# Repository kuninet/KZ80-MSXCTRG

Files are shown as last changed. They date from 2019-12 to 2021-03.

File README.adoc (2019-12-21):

== KZ80シリーズ MSX カートリッジスロットボード

=== 概要
* SBC8080バスなどに接続する MSX ROMカセット カートリッジスロットボードですです。試作段階です。

=== 注意
* KZ80-CPUB REV3 のZ80専用信号線バスと、KZ80-IOB REV2以降(アドレスデコードの関係で...)のAポートを使用します。またメモリーボードKZ80-1MSRAMのパターンカット等の改造が必要です。

=== ライセンス
* 本プロジェクトのデータはMITライセンスのもとで公開します。

=== 参考
* http://ngs.no.coocan.jp/doc/wiki.cgi/datapack?page=7%BE%CF+MSX2%2B%B2%F3%CF%A9%CE%E3

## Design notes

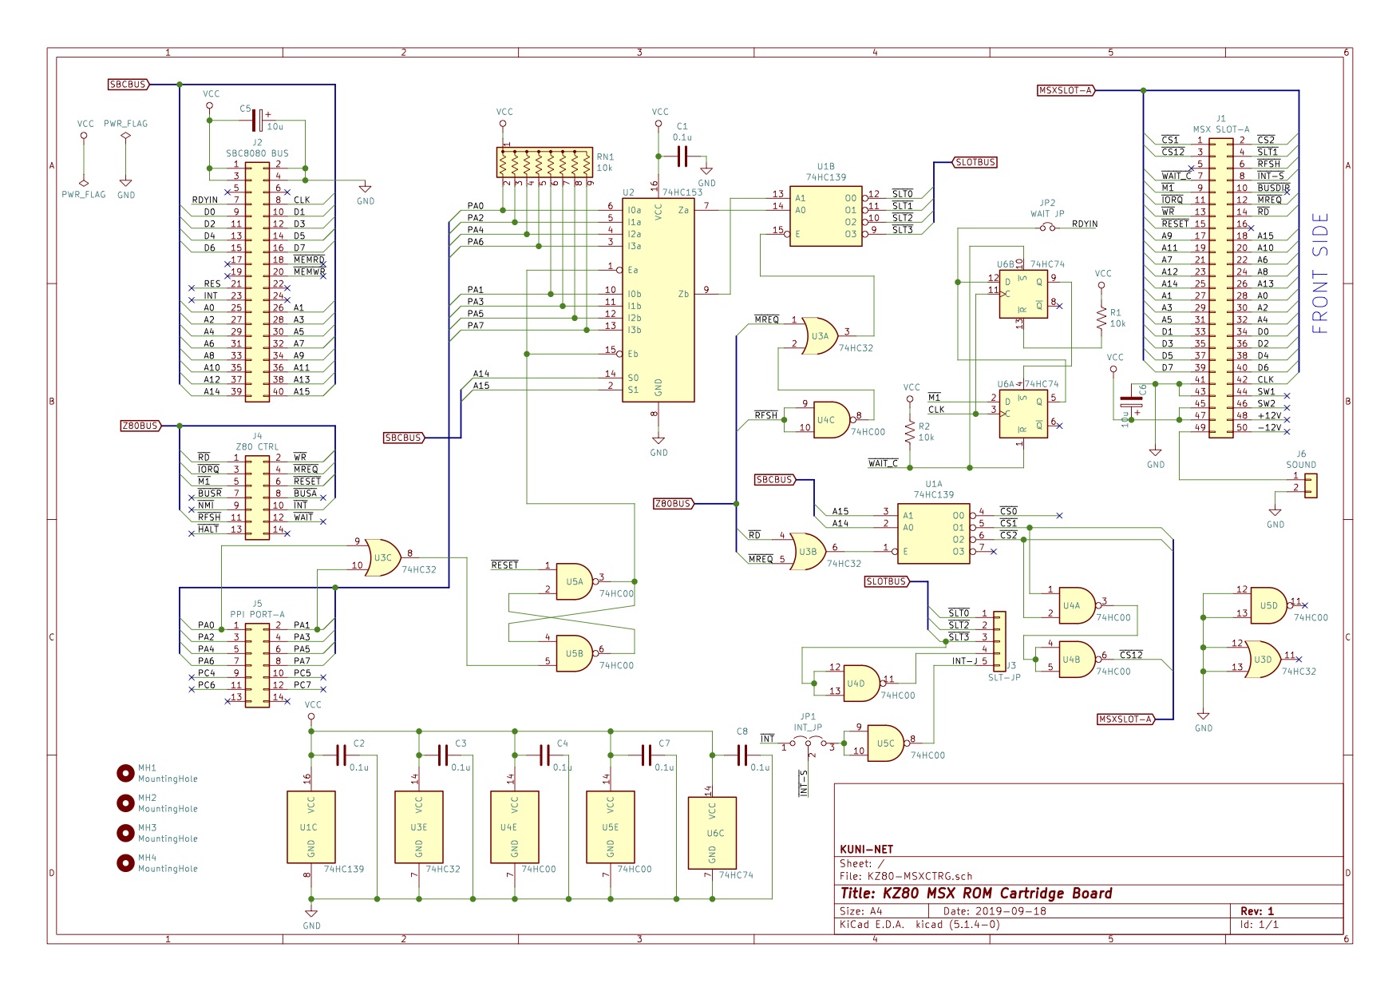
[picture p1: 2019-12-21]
image/KZ80-MSXCTRG-REV1.jpg

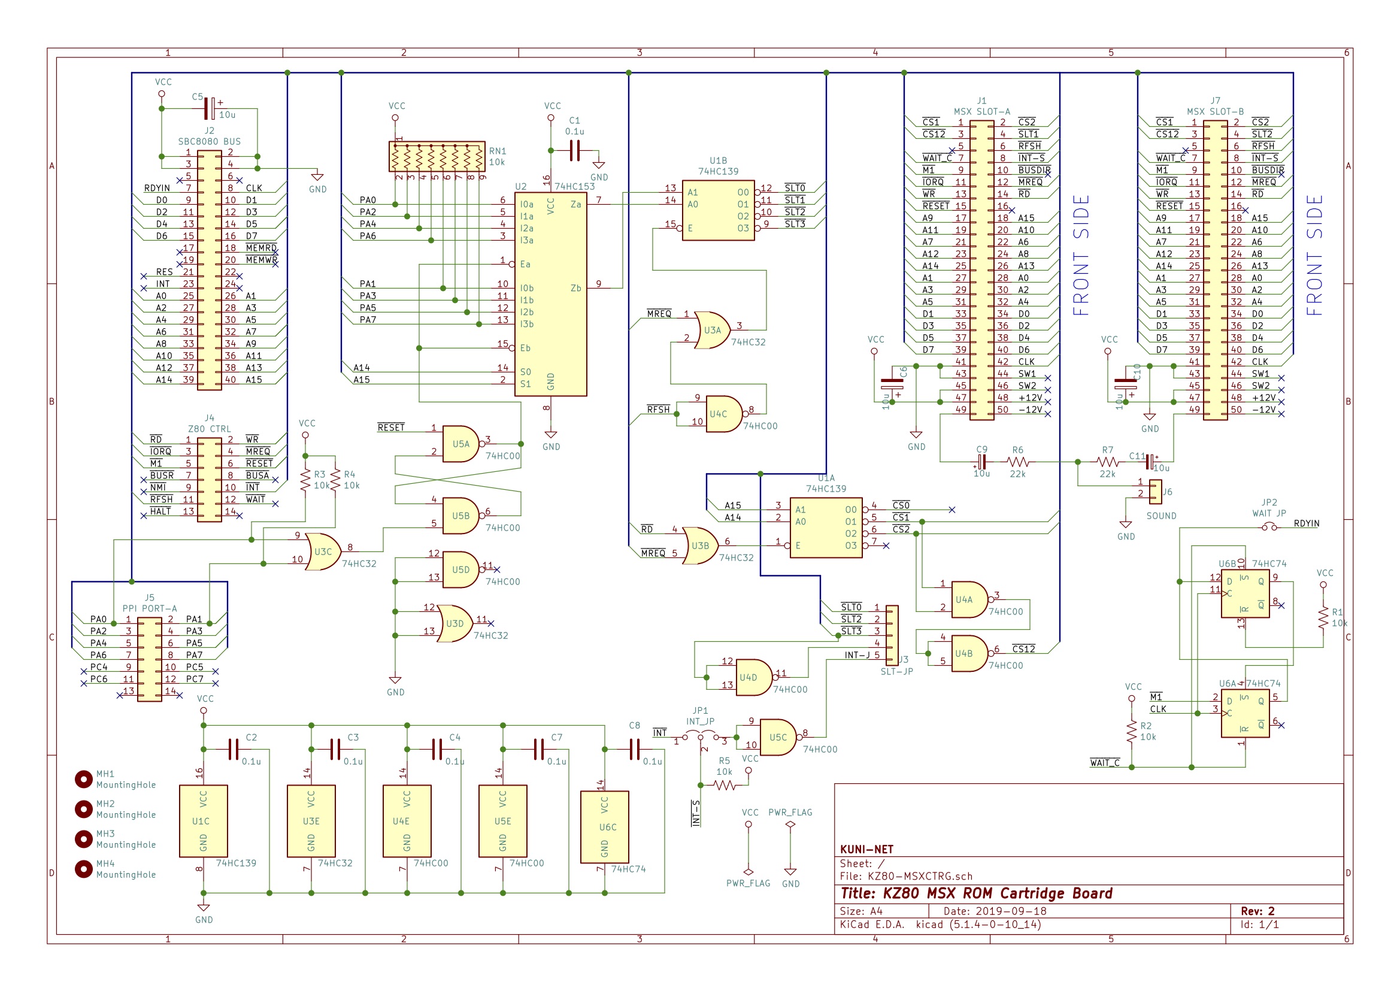
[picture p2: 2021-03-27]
image/KZ80-MSXCTRG-REV2.jpg

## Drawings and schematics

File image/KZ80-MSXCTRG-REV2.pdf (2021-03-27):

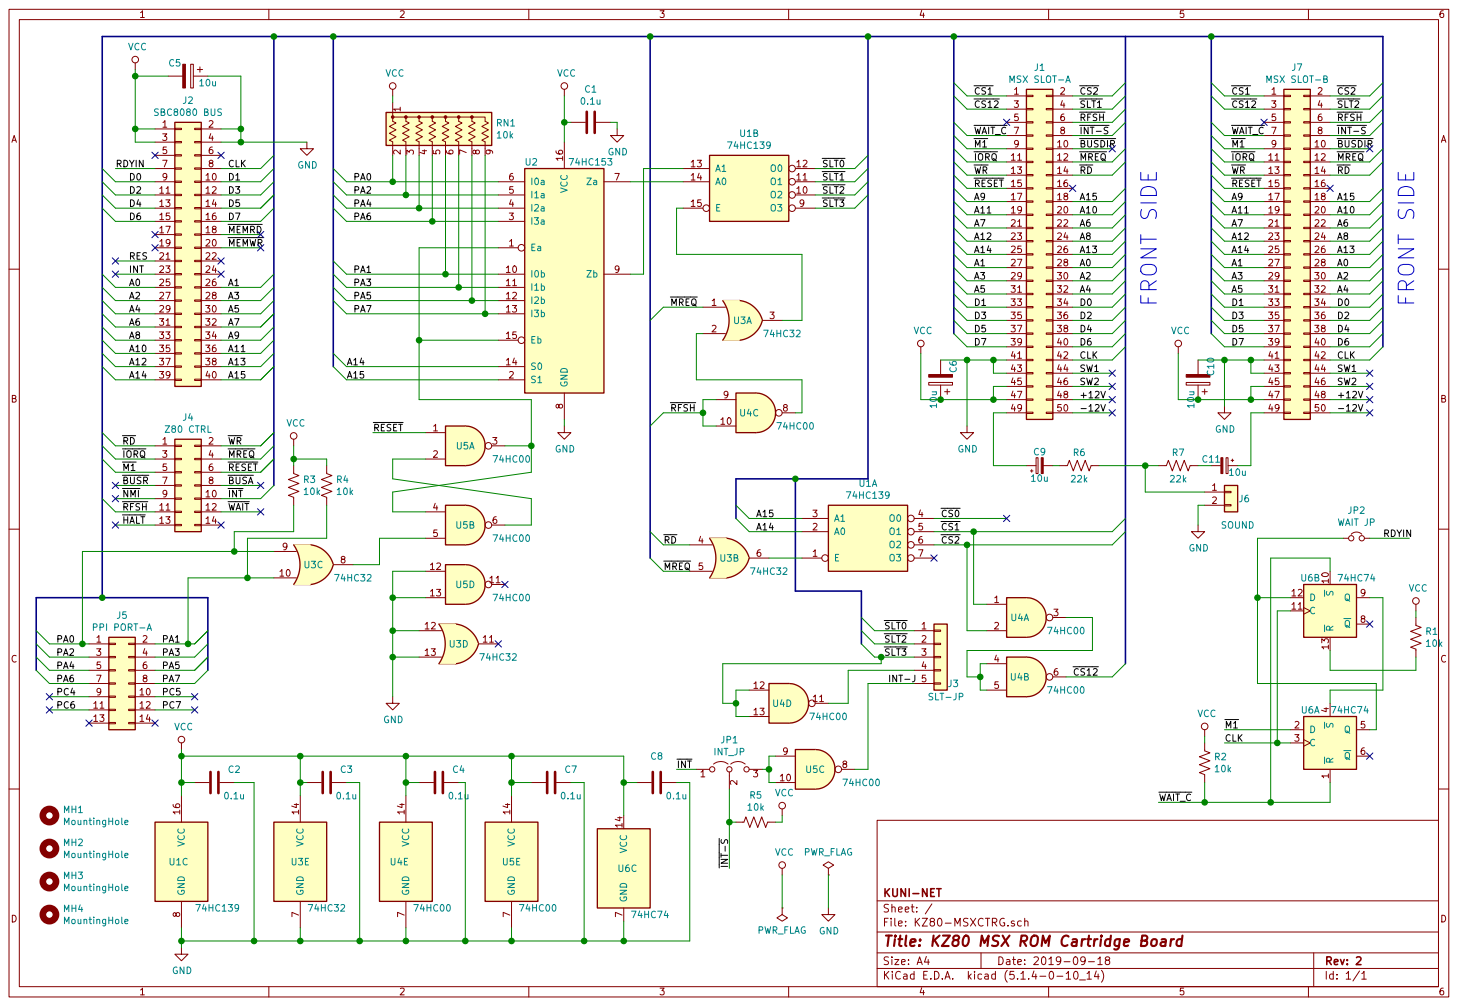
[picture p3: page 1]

File: KZ80-MSXCTRG.sch Sheet: / KUNI-NET

Id: 1/1 Title: KZ80 MSX ROM Cartridge Board

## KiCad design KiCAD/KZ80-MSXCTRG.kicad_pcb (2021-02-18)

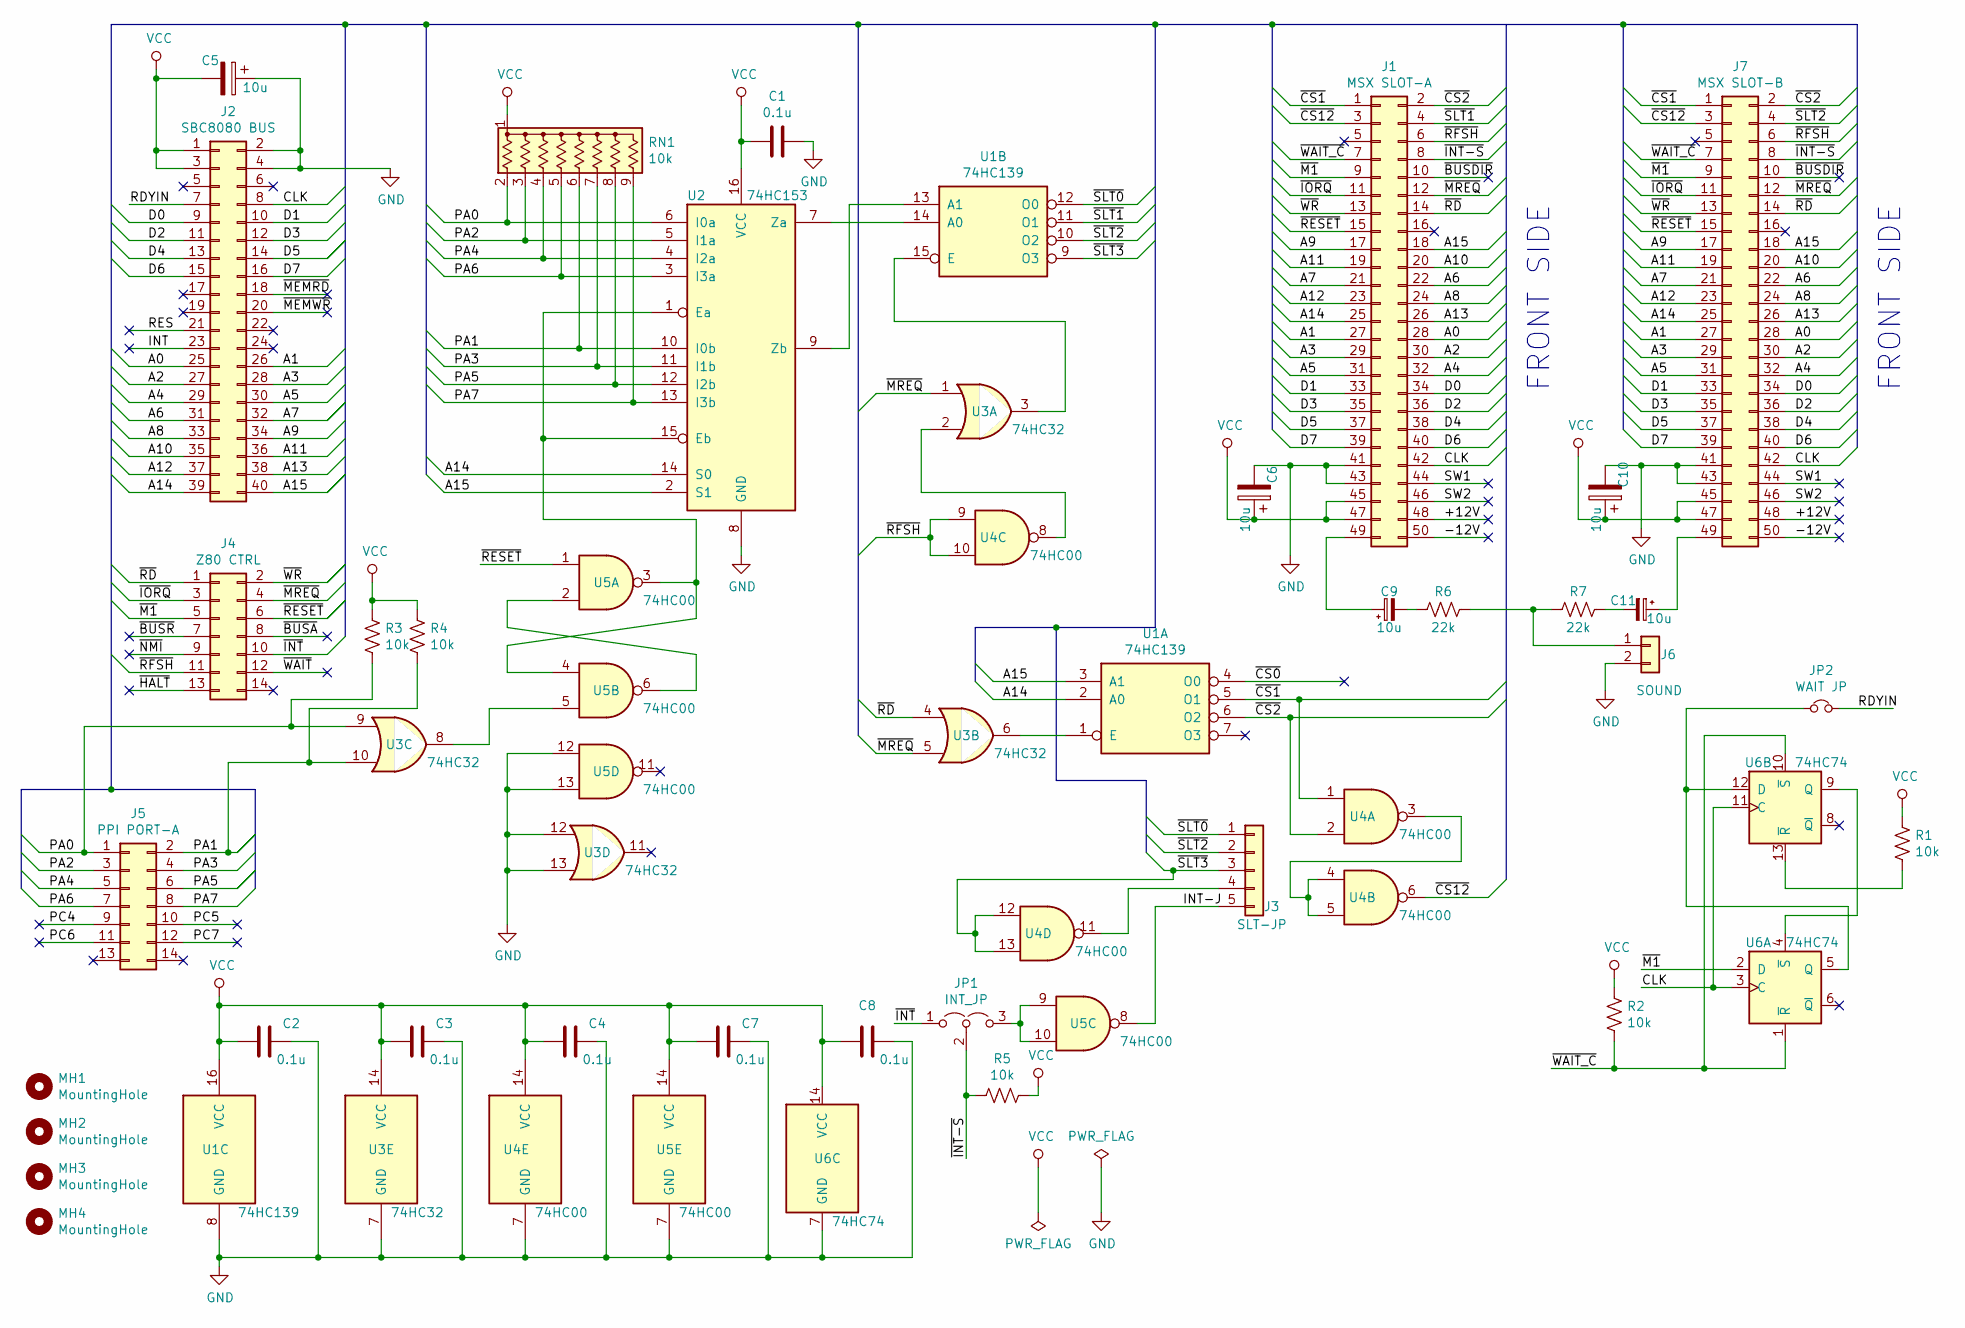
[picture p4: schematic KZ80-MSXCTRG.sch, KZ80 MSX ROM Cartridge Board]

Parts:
C1, C2, C3, C4, C7, C8: 0.1u; C_Disc_D3.0mm_W1.6mm_P2.50mm
C5, C6, C9, C10, C11: 10u; CP_Radial_D5.0mm_P2.50mm
J1: MSX SLOT-A; PCB_Edge_Conn_2x25_P2.54mm_Vertical
J2: SBC8080 BUS; PinHeader_2x20_P2.54mm_Horizontal
J3: SLT-JP; PinHeader_1x05_P2.54mm_Horizontal
J4: Z80 CTRL; PinHeader_2x07_P2.54mm_Vertical
J5: PPI PORT-A; PinHeader_2x07_P2.54mm_Vertical
J6: SOUND; PinHeader_1x02_P2.54mm_Horizontal
J7: MSX SLOT-B; PCB_Edge_Conn_2x25_P2.54mm_Vertical
JP1: INT_JP; PinHeader_1x03_P2.54mm_Vertical
JP2: WAIT JP; PinHeader_1x02_P2.54mm_Vertical
MH1, MH2, MH3, MH4: MountingHole; MountingHole_3.2mm_M3
R1, R2, R3, R4, R5: 10k; R_Axial_DIN0207_L6.3mm_D2.5mm_P10.16mm_Horizontal
R6, R7: 22k; R_Axial_DIN0207_L6.3mm_D2.5mm_P10.16mm_Horizontal
RN1: 10k; R_Array_SIP9
U1: 74HC139; DIP-16_W7.62mm_Socket
U2: 74HC153; DIP-16_W7.62mm_Socket
U3: 74HC32; DIP-14_W7.62mm_Socket
U4, U5: 74HC00; DIP-14_W7.62mm_Socket
U6: 74HC74; DIP-14_W7.62mm_Socket

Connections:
/+12V: J1.48, J7.48
/-12V: J1.50, J7.50
/A0: J1.28, J2.25, J7.28
/A1: J1.27, J2.26, J7.27
/A2: J1.30, J2.27, J7.30
/A3: J1.29, J2.28, J7.29
/A4: J1.32, J2.29, J7.32
/A5: J1.31, J2.30, J7.31
/A6: J1.22, J2.31, J7.22
/A7: J1.21, J2.32, J7.21
/A8: J1.24, J2.33, J7.24
/A9: J1.17, J2.34, J7.17
/A10: J1.20, J2.35, J7.20
/A11: J1.19, J2.36, J7.19
/A12: J1.23, J2.37, J7.23
/A13: J1.26, J2.38, J7.26
/A14: J1.25, J2.39, J7.25, U1.2 (A0), U2.14 (S0)
/A15: J1.18, J2.40, J7.18, U1.3 (A1), U2.2 (S1)
/CLK: J1.42, J2.8, J7.42, U6.3 (C), U6.11 (C)
/D0: J1.34, J2.9, J7.34
/D1: J1.33, J2.10, J7.33
/D2: J1.36, J2.11, J7.36
/D3: J1.35, J2.12, J7.35
/D4: J1.38, J2.13, J7.38
/D5: J1.37, J2.14, J7.37
/D6: J1.40, J2.15, J7.40
/D7: J1.39, J2.16, J7.39
/INT: J2.23
/INT-J: J3.5, U5.8
/PA0: J5.1, R3.2, RN1.2 (R1), U2.6 (I0a), U3.9
/PA1: J5.2, R4.2, RN1.6 (R5), U2.10 (I0b), U3.10
/PA2: J5.3, RN1.3 (R2), U2.5 (I1a)
/PA3: J5.4, RN1.7 (R6), U2.11 (I1b)
/PA4: J5.5, RN1.4 (R3), U2.4 (I2a)
/PA5: J5.6, RN1.8 (R7), U2.12 (I2b)
/PA6: J5.7, RN1.5 (R4), U2.3 (I3a)
/PA7: J5.8, RN1.9 (R8), U2.13 (I3b)
/PC4: J5.9
/PC5: J5.10
/PC6: J5.11
/PC7: J5.12
/RDYIN: J2.7, JP2.2
/RES: J2.21
/SW1: J1.44, J7.44
/SW2: J1.46, J7.46
/~BUSA: J4.8
/~BUSDIR: J1.10, J7.10
/~BUSR: J4.7
/~CS0: U1.4 (O0)
/~CS1: J1.1, J7.1, U1.5 (O1), U4.1
/~CS2: J1.2, J7.2, U1.6 (O2), U4.2
/~CS12: J1.3, J7.3, U4.6
/~HALT: J4.13
/~INT: J4.10, JP1.1 (A)
/~INT-S: J1.8, J7.8, JP1.2 (C), R5.2
/~IORQ: J1.11, J4.3, J7.11
/~M1: J1.9, J4.5, J7.9, U6.2 (D)
/~MEMRD: J2.18
/~MEMWR: J2.20
/~MREQ: J1.12, J4.4, J7.12, U3.1, U3.5
/~NMI: J4.9
/~RD: J1.14, J4.1, J7.14, U3.4
/~RESET: J1.15, J4.6, J7.15, U5.1
/~RFSH: J1.6, J4.11, J7.6, U4.9, U4.10
/~SLT0: J3.1, U1.12 (O0)
/~SLT1: J1.4, U1.11 (O1)
/~SLT2: J3.2, J7.4, U1.10 (O2)
/~SLT3: J3.3, U1.9 (O3), U4.12, U4.13
/~WAIT: J4.12
/~WAIT_C: J1.7, J7.7, R2.2, U6.1 (~R), U6.10 (~S)
/~WR: J1.13, J4.2, J7.13
GND: C1.1, C2.1, C3.1, C4.1, C5.1, C6.2, C7.1, C8.1, C10.2, J1.41, J1.43, J2.2, J2.4, J6.2, J7.41, J7.43, U1.8 (GND), U2.8 (GND), U3.7 (GND), U3.12, U3.13, U4.7 (GND), U5.7 (GND), U5.12, U5.13, U6.7 (GND)
unnamed: C9.1, J1.49
unnamed: C9.2, R6.2
unnamed: C11.1, J7.49
unnamed: C11.2, R7.1
unnamed: J3.4, U4.11
unnamed: J6.1, R6.1, R7.2
unnamed: JP1.3 (B), U5.9, U5.10
unnamed: JP2.1, U6.5 (Q), U6.12 (D)
unnamed: R1.2, U6.13 (~R)
unnamed: U1.1 (E), U3.6
unnamed: U1.13 (A1), U2.9 (Zb)
unnamed: U1.14 (A0), U2.7 (Za)
unnamed: U1.15 (E), U3.3
unnamed: U2.1 (Ea), U2.15 (Eb), U5.3, U5.4
unnamed: U3.2, U4.8
unnamed: U3.8, U5.5
unnamed: U4.3, U4.4, U4.5
unnamed: U5.2, U5.6
unnamed: U6.4 (~S), U6.9 (Q)
VCC: C1.2, C2.2, C3.2, C4.2, C5.2, C6.1, C7.2, C8.2, C10.1, J1.45, J1.47, J2.1, J2.3, J7.45, J7.47, R1.1, R2.1, R3.1, R4.1, R5.1, RN1.1 (common), U1.16 (VCC), U2.16 (VCC), U3.14 (VCC), U4.14 (VCC), U5.14 (VCC), U6.14 (VCC)

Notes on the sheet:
FRONT SIDE

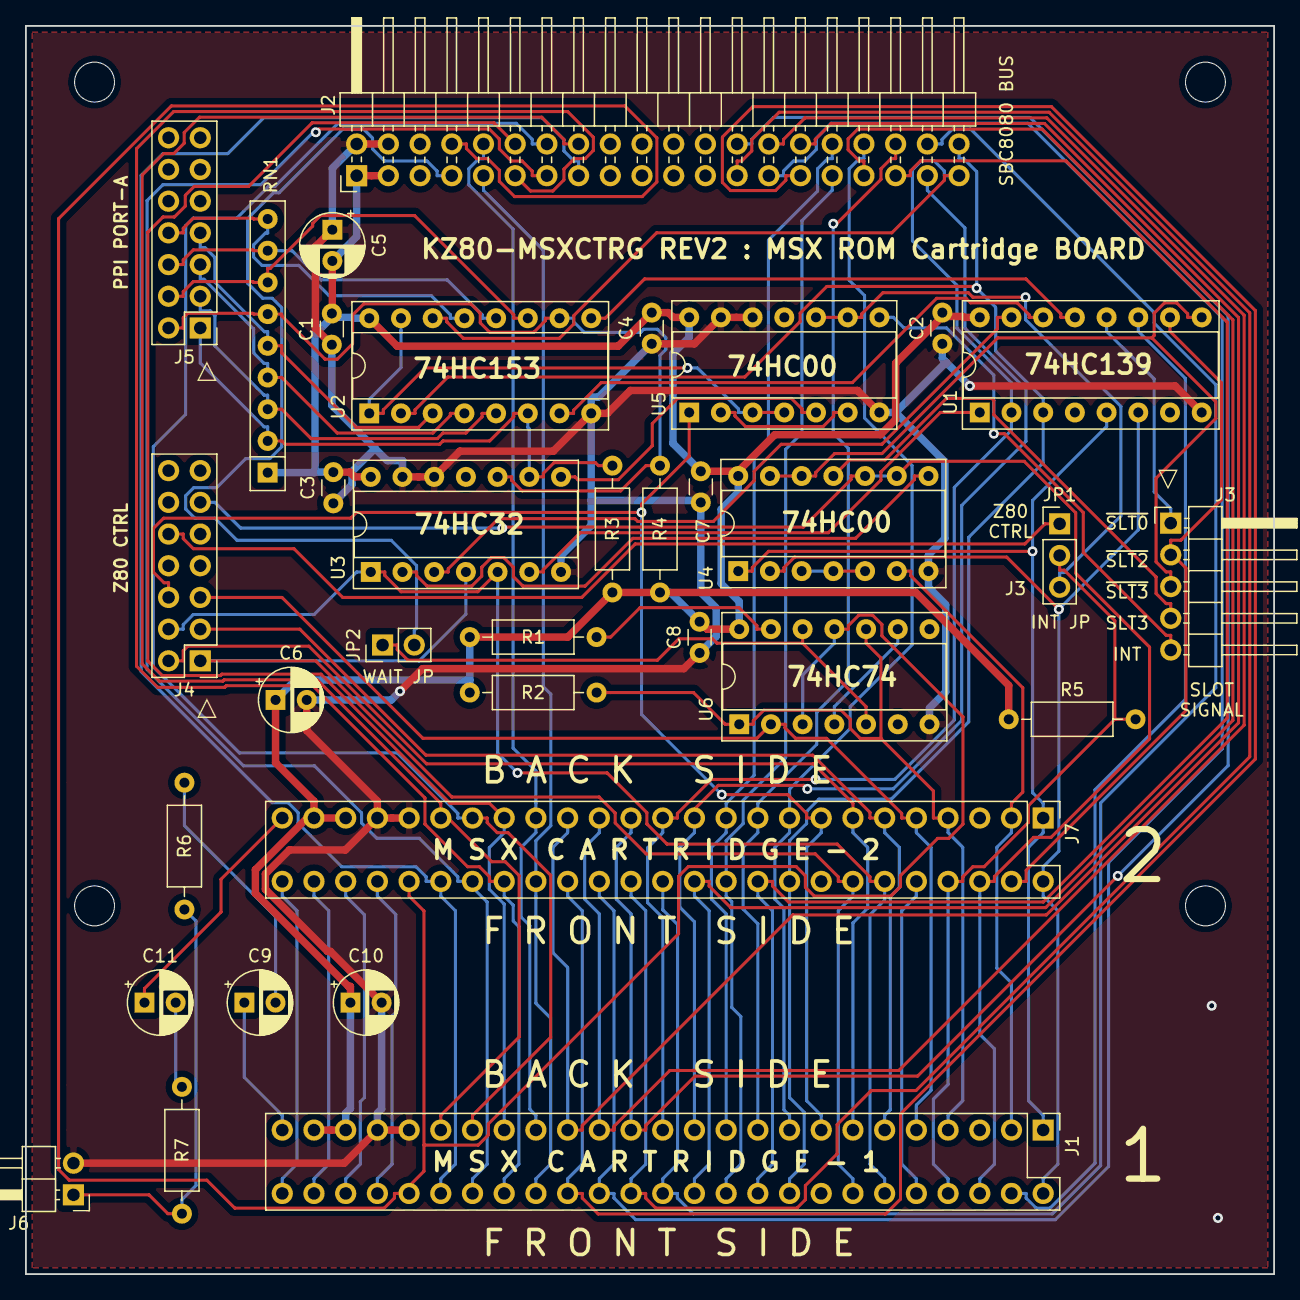
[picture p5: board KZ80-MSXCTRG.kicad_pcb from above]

Board: 2 copper layers, 100.0 x 100.0 mm, 38 parts (0 on the bottom side), 78 nets.

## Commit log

2019-09-22 初期コミット
    [KZ80-MSXCTRG.kicad_pcb, KZ80-MSXCTRG.sch, _saved_KZ80-MSXCTRG.sch]
2019-09-24 割り込み信号を外部端子と切り替えるジャンパ装備
    [KZ80-MSXCTRG.sch, _saved_KZ80-MSXCTRG.sch]
2019-09-30 74HC153コントロールをPPI出力で暫定実施
    [KZ80-MSXCTRG.sch]
2019-10-01 回路改良
    [KZ80-MSXCTRG.sch]
2019-10-05 74HC153コントロール用RS-FF追加
    [KZ80-MSXCTRG.dsn, KZ80-MSXCTRG.sch]
2019-10-05 プリントパターン見直し
    [KZ80-MSXCTRG.dsn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]
2019-12-21 REV1基板(1WAIT回路追加) ガーバーデータ出力
    [KZ80-MSXCTRG-B_Cu.gbl, KZ80-MSXCTRG-B_Mask.gbs, KZ80-MSXCTRG-B_SilkS.gbo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]
2019-12-21 REV1回路図面PDF/jpg差し替え
2021-02-08 2スロット対応
    [KZ80-MSXCTRG.sch]
2021-02-08 パターン改良ぬ
    [KZ80-MSXCTRG.dsn, KZ80-MSXCTRG.kicad_pcb, KZ80-MSXCTRG.sch]
2021-02-18 ガーバーデータ出力
    [KZ80-MSXCTRG-B_Cu.gbl, KZ80-MSXCTRG-B_Mask.gbs, KZ80-MSXCTRG-B_SilkS.gbo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]
2021-03-27 REV2回路図イメージ出力
